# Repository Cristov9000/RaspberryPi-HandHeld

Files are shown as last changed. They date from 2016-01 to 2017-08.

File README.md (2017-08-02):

# RaspberryPi handheld
Hello Everyone!

Thank you for checking out my instructions on how to build your own RaspberryPi handheld. The RaspberryPi handheld is a Raspberry Pi powered handheld system that runs RetroPie giving you the ability to play games from the NES, SNES, Genesis, GameBoy, GameGear, Atari, Playstation, arcade games (MAME) and lots of other systems. In designing this handheld I made sure to include enough buttons for full Playstation emulation so there is a d-pad, start, select, A, B, X, Y, L1, R1, L2, and R2 buttons. The SuperGameGirl is powered by a 6000mAh LiPo battery that gives it around 7 hours battery life. The battery is rechargeable via microUSB on the bottom of the handheld with a status LED to showing charging and fully charged states. The power supply in the unit allows it to be charged while you are playing as well. A microcontroller distributes the power from the powersupply to the RaspberryPi, screen, amp, and other peripherals while ensuring that the Pi is shutdown properly when the switch its turned off. This is required to prevent SD card corruption and loosing your precious saved games! Using RetroPie allows the emulators to be quickly set-up, brings saving to systems that previously didn't have the ability to save games, allows the adding of games via USB and uses EmulationStation as a nice clean way to organize everything. If this sounds like fun, keep reading! The detailed instructions on how to assemble one can be found here:  https://imgur.com/a/gFhk7

Here you will find the .stl files that you will need to 3D print the case as well as the softwear that you will need to load onto the Pi and the ATTiny85.

****I am pleased to announce that Kitsch-Bent will be taking over production of these boards and stocking them so people can buy then whenever they want.  This both frees me up to create new retrogaming projects and give everyone a constant supply of parts for the project from an established and knowledgeable retrogaming company.  Its a win for everyone!  If you would like to order parts please see http://www.supergamegirl.com/. Thank you to everyone for your support, I really appreciate it and never expected this project to blow up like that.  But, as they say, on to the next one!

- 2/29/2016 - Another batch of boards were ordered.  I expect them in 25 days or less from today.  Boards are still available to order.
- 3/5/2016 - The boards are in production.  I expect them in 20 days or so.  There are still a few boards left in this batch available for order.
- 3/12/2016 - The boards are out of production and are being mailed to me.  Expected delivery date is late next week.
- 3/18/2016 - The boards have arrived to me from the manufacturer, I will pack and ship tonight and tomorrow.  Thank you everyone for your support.

---------------------------------------------------------------------------------------------------------------------------------

Also, I am a mechanical engineer so I am always looking for coding and circuit recomendations from you software and EE people.  I would love to hear how to make this project better and more efficient!

Known Issues (I would love to hear a solution): 

1. On one unit there is a static/hum noise from the speaker at all times that the other unit doesn't have. I don't know why and figure out the difference. 

2. On one unit the display has some static on it, it doesn't effect the gameplay but you can see it if you are really looking for it and it is pissing me off. It is almost like the display is low on power. Maybe there is a little too much voltage drop across the MOSFET... I dunno 

3. I originally designed it to have the ATTiny run on 3.3V to make it easier to talk to the Pi and to save power (hence the second power supply) but I could not get it to switch the MOSFET and have the display still switch on and off with just 3.3V despite all data sheets saying it should work. Anyone know why? I turned it up to 5v and added a voltage divider to talk to the Pi and it works but probably not as efficiently as it should be.

Thank you everyone!

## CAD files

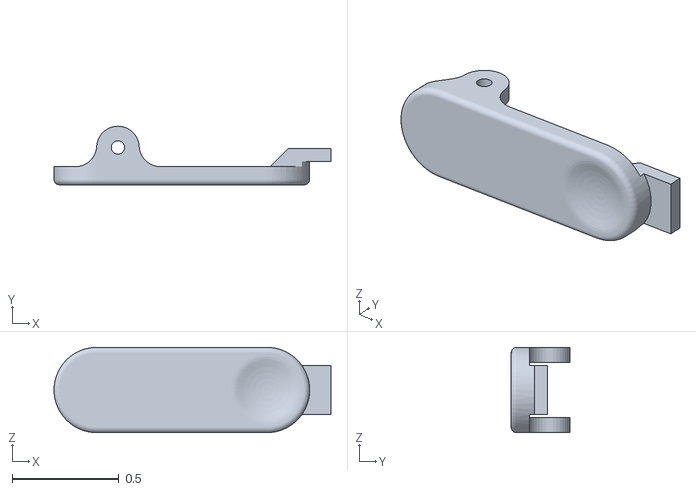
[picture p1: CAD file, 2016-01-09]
CaseFiles/ShoulderButton.STL
1.30 x 0.275 x 0.4

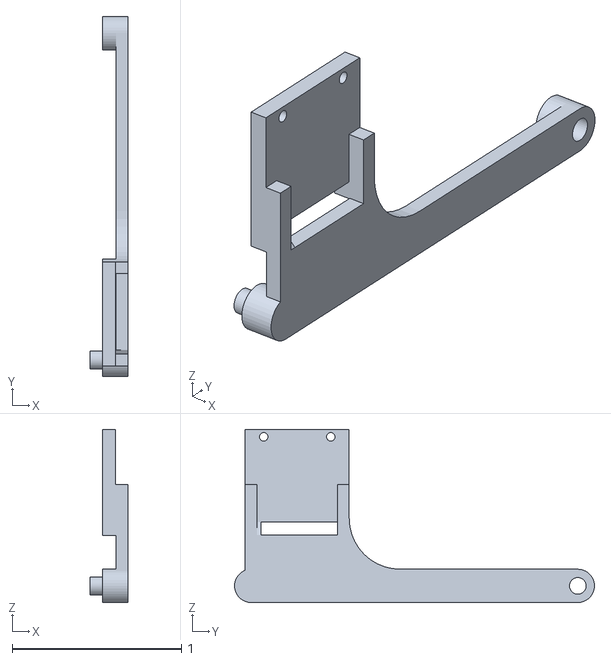
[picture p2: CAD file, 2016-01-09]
CaseFiles/PiBracket.STL
0.225 x 2.13 x 1.02

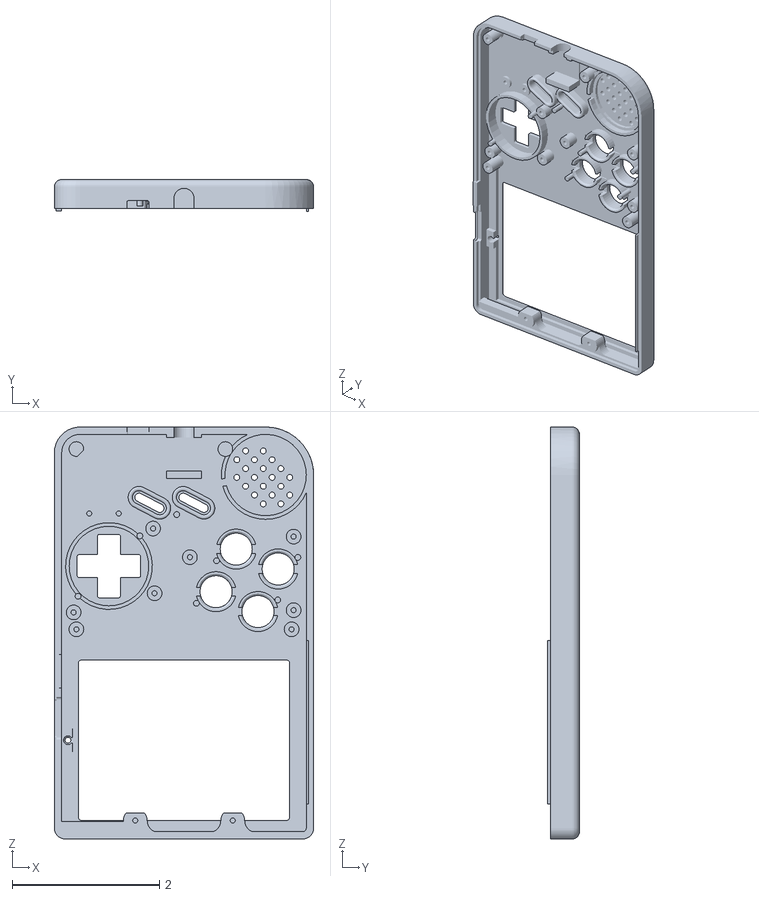
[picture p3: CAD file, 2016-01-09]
CaseFiles/FrontCase.STL
3.52 x 0.434 x 5.60

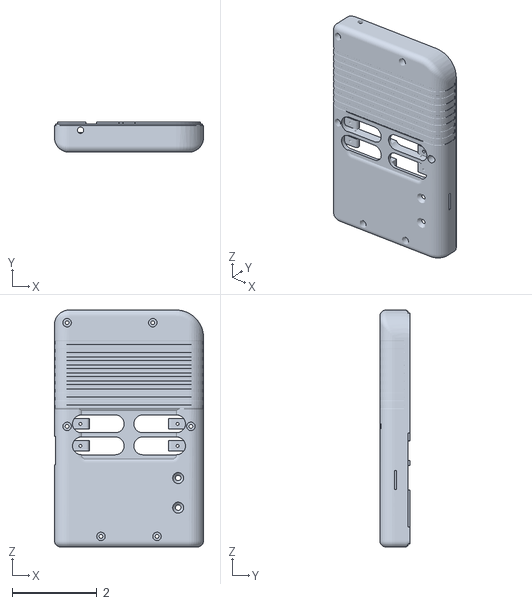
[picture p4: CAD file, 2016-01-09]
CaseFiles/BackCase.STL
3.52 x 0.719 x 5.60

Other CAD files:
CaseFiles/ShoulderButtonFlat.STL

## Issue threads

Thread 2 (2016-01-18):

Share schematics to help troubleshoot known issues

pslogic, 2016-01-18:
Knowing how things are wired up would facilitate further discussion on what may be causing the issues noted in the README. Is this something that can be pushed into the repo at this time?

alenaksu, 2016-07-24:
+1

TheeJayRed, 2016-07-25:
+1
Would love a schematic if possible.

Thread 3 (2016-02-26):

Audio Static Issue

defenestration, 2016-02-26:
Since you it mentioned on the Readme, I recently had a similar issue with static hiss out of the audio jack when no other audio is playing on my Rpi2.

To fix,in /boot/config.txt, set

`disable_audio_dither=1`

and reboot.

Cristov9000, 2016-02-26:
I do have that in my config.txt but it doesn't seem to help for some reason.  I am going to try to open up the unit with the issue and move the grounds around for the audio circuit

defenestration, 2016-02-26:
Thought i would mention it since I did not see that setting mentioned through the many guides i was looking through to setup my own portible gamepi.  Good luck!

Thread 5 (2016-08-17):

Power supply doesn't turn off after switch is turned off

kvchen, 2016-08-17:
I'm running into an issue where the ATtiny won't power off the Adafruit 1000C power supply after the switch is turned off. When I power off the switch, the screen blanks and the Raspberry Pi goes through its usual shutdown routine, finishing with just the static red power light. After about 10 seconds, both the power supply light and the Raspberry Pi power lights are still on, indicating that the power supply was not switched off. Trying to turn the switch back on will turn the power light on (on the front case), but the Raspberry Pi will remain off. I end up having to disconnect the battery in order to shut everything down. Aside from that, everything works fine - when I connect the battery, everything is powered off until I flip the switch on; it's just shutting down that doesn't quite work.

My guess is that the ATtiny doesn't receive the message that the Raspberry Pi is shutting down, so it never ends up killing the power. I don't have the gerber for the `SGGBackBoard`, so it's pretty hard for me to debug this one.

First of all, when does `rpistate` get set to LOW? `pm4.c` shows that it's defined on `PB3`, but I'm not sure where that's hooked up to on the PCB. Secondly, the main circuitboard shows `RX`, but the associated GPIO pin is 18, not RX (which is GPIO 15).

I'm currently using a Raspberry Pi v3 and the included ATtiny85 that I got from the SuperGameGirl products page.

kvchen, 2016-08-27:
Resolved. The issue is that the TX pin on the RPi3 doesn't quite hit a low enough voltage when the Pi shuts down, so connect the TX pin on the SuperGameGirl board to pin 23 on the Raspberry Pi 3 instead. Nothing else needs to be changed.

christianhaitian, 2016-10-21:
Just a correction on this.  It should be connect the TX pin on the SuperGameGirl board to GPIO 23 (PIN 16) on the Raspberry PI 3 to resolve the shutdown issue for this project using the latest version of RetroPie.

Closed 2016-08-27.

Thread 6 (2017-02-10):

Raspberry Pi shuts down but does not power off

p3zip, 2017-02-10:
Power switch on turns on Pi and video, power switch off turns off video and issues shutdown to Pi, but the Pi stays powered on.  Not sure how to troubleshoot this one.

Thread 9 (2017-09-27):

Pi shut down but won't restart after using the spdt switch

Edjuh82, 2017-09-27:
When i turned off the pi using the spdt switch it won't restart after turning the switch back on. My powerboost also stays on during the shut off. It turns off the screen and turns it on but not the pi.

Anyone know how to solve this?

Using a raspberry pi 3 and used this guide aswell as the other one posted on reddit.

mattc74, 2017-10-04:
The pi3 is different in that it uses a software UART. The physical uart is used for bluetooth on the pi3 so it's now a software emulated uart on the gpio pins.

I had to switch on the console (opposite to pi2) in raspi-config to generate a voltage for the attiny to sense, I also dropped a small capacitor (10uF) across to smooth it out, works perfectly!

spedga, 2018-02-13:
@mattc74 I'm also having this issue. Would you mind explaining "I had to switch on the console (opposite to pi2) in raspi-config to generate a voltage for the attiny to sense" in a bit more detail? I'm fairly new to editing configs with the raspberry pi. It seems like this is the last step I have before screwing everything in place and finally finishing this project and getting down to some gaming!

mattc74, 2018-02-13:
You can either:

Enable the console in sudo raspi-config

Or

 you need to change enable_uart=1 in /boot/config.txt

spedga, 2018-02-14:
I did both of these @mattc74 but it's still not booting after shutting down. Do you have anymore ideas for troubleshooting steps I could try?

BioHaZard1, 2018-03-18:
Must be a problem with wiring then as I have just done this successfully.

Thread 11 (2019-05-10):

Retropie-HH is stuck in bootloop

pyrocide, 2019-05-10:
I can hit the "four raspberry" screen, no OS boot text loads, reboots to AV2, then to AV1 and rainbow splash screen and just bootloops like this forever until battery is pulled.

Plugged direct into the rpi2 and it boots just fine, except still trying to figure out the new adafruit control cfg files.

Ive de/resoldered all components checking for bad leads or contacts/wires, It all works except for when its powered by battery or charger breakout. Has anyone happened to run into this or know what the problem could be?

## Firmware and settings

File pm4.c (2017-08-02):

//*********************************************************
//
//  pm4.c - by Chris Duerden
//	Power Management program for ATTiny85
//	9/9/2015	RevA - Initial Release
//	9/20/2015	RevB - Added sw debounce to while loop
//	9/30/2015	RevC - Fixed issue with power switch being 
//						turned off before full Rpi boot
//	10/20/2015	RevD - Reordered pins to match BoardRevB
//	
//	Function: Monitors power switch, if on, power on power 
//		supply and screen, if off safe power down RPi and
//		then shutdown power supply
//
//*********************************************************

#define F_CPU 1000000	//1MHz

#include <avr/io.h>
#include <avr/interrupt.h>
#include <avr/sleep.h>
#include <util/delay.h>

#define rpistate 	PB3
#define rpireset 	PB4
#define pswitch 	PB2
#define pper 		PB0
#define psupply 	PB1

int rpiSD = 0;
int rpiPU = 0;
int i = 0;
int j = 0;
int switchoff = 0;
int debounce = 0;
int timeOUT = 0;

void sleepNOW()   //function to put attiny85 into low power sleep mode      
   {			  
	DDRB = 0b00000010;
	PORTB = 0b00000000;	//set everything as input to save power
		
	cli();
	GIMSK |= (1 << PCIE);	//Set up pin change interrupt to wake on power on
	PCMSK |= (1 << PCINT2);
	set_sleep_mode(SLEEP_MODE_PWR_DOWN);  //sleep mode
	sleep_enable();
	sei();
	sleep_cpu();
	
	sleep_disable();  //resume here on wake up
	cli();
	PCMSK &= ~(1 <<PCINT2); 	//turn off interrupt
	sei();		
	}  
	
void wakeUP()
	{		
	DDRB = 0b00010001;		//on wake up set outputs 
	PORTB = 0b00000001;		//and turn on powersupply and screen/amp
	}
	
void shutDOWN()
	{
		while(rpiSD == 0)					//wait for RPi to shutdown properly
		{
			if((PINB & (1 << rpistate)) == 0)	//When this goes low RPi is shutting down
			{
				rpiSD++;
			}
			if(PINB & (1 << pswitch))			//If power switch turns back on turn on screen/amp
			{
				wakeUP();
			}
			else
			{
				PORTB &= ~(1 << pper);				//Immediately kill screen/amp
			}
		}
		for(j=0; j < 75; j++)					//wait 10 seconds for RPi to finish
		{
			_delay_ms(100);
			if (PINB & (1 << pswitch))		//If power switch turns back on turn on screen/amp
			{
				wakeUP();
			}
			else
			{
				PORTB &= ~(1 << pper);				//Immediately kill screen/amp
			}
		}
		if(PINB & (1 << pswitch))			//If power switch is on, reset RPi
		{
			wakeUP();
			PORTB |= (1 << rpireset);
			_delay_ms(10);	
			PORTB &= ~(1 << rpireset);		
		}
		else								// If power switch is off, turn off power supply and sleep
		{
			sleepNOW();
		}
	}	
	
ISR(PCINT0_vect)	//Interrupt service routine
	{
	    wakeUP();	//Wake up on interrupt
	}

//Main
int main(void)
{
	DDRB = 0b00010011;
	PORTB = 0b00000000;
	 
	for(i = 0; i < 6; i++)	//Blink 3X on initial power up as sanity check
	{
		PORTB ^= (1 << pper);
		_delay_ms(100);	
	}
	
	ADCSRA &= ~(1<<ADEN);	//Turn off ADC - not needed - to save power
	
	if((PINB & (1 << pswitch)) == 0)	//What is the state of the power switch when powered on.
	{	
		sleepNOW();
	}
	else								//if on, turn everything on
	{
		wakeUP();
	}
//Loop	
	while(1)
	{
		if((PINB & (1 << pswitch)) == 0)  //Debounce switch flip to off
		{
			if(debounce < 200)
			{
				debounce++;
			}
			if(debounce == 200)
			{
				switchoff = 1;
			}	
		}
		else
		{
			debounce = 0;
		}
	
	
		if(switchoff == 1)		//Keep polling for power switch to turn off
		{	
			PORTB &= ~(1 << pper);				//Immediately kill screen/amp
			rpiSD = 0;							
			if((PINB & (1 << rpistate)) == 0) //  If turned off prior to full RPi boot
			{
				rpiPU = 0;
				timeOUT = 0;
				while(rpiPU == 0)
				{
					timeOUT++;
					_delay_ms(10);
					if(PINB & (1 << rpistate) || timeOUT == 2000)	//When this goes High RPi is powered up or times out
					{
						rpiPU++;
						_delay_ms(1000);
					}
						
					if (PINB & (1 << pswitch))		//If power switch turns back on turn on screen/amp
					{
						wakeUP();
					}
					else
					{
						PORTB &= ~(1 << pper);				//Immediately kill screen/amp
					}	
				}
				if (PINB & (1 << pswitch) == 0)
				{
					shutDOWN();
				}
				else
				{
					wakeUP();
				}
			}
			else
			{
				shutDOWN();
			}
			switchoff = 0;
		}
	}	
	return 0;	
}

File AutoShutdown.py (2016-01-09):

#*************************************************************************
#
# autoshutdown.py  -  by: Chris Duerden
# Raspberry Pi safe shutdown program to interface with ATTiny85
# 9/8/2015      RevA - Initial Release
# 9/28/2015     RevB - removed ", pull_up_down = GPIO.PUD_UP" from input
#
# Function:  This program is designed to safely shut down a Raspberry Pi
# when a GPIO pin is brought low by a power management circuit
# 
#*************************************************************************

#Import
import RPi.GPIO as GPIO
import time
import os

#Setup
GPIO.setmode(GPIO.BCM) #Set Pin numbers to GPIO numbering  
GPIO.setup(18, GPIO.IN) #Set GPIO18 as input
GPIO.setup(23, GPIO.OUT, initial=GPIO.HIGH) #Set GPIO23 as constant output

#Define Program to shutdown RPi
def shutdown(pin):  
	os.system("sudo shutdown -h now")
	
#Setup Interrupt on GPIO18 when Grounded
GPIO.add_event_detect(18, GPIO.FALLING, callback = shutdown, bouncetime = 200)   

#Main
while 1:
        time.sleep(1) #Prevent Program for ending only

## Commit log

2016-01-09 Create AutoShutdown.py
    This program needs to be downloaded on your Raspberry Pi and then setup to start up on boot
2016-01-13 Update and rename READ ME to READ ME 3D Printing
2016-01-15 Update board availability!
2016-01-16 Boards SOLD OUT
2016-01-27 Boards inbound!
2016-02-01 Boards packaged and ready to go!
2016-02-26 BOARDS ARE BACK IN PRODUCTION
2016-03-07 Boards in Production!
2016-03-12 Boards Finished Production!
2016-03-18 Boards are shipping!
